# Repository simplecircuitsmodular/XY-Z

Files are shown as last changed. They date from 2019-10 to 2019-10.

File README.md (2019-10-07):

# XY-Z

This is a 16 step 2 dimensional CV sequencer. Each step is controlled by a potentiometer. The pots are laid out in a 4x4 grid, and 2 inputs (X and Y) allow you to move between rows and columns. The module is based on an ATMega 328 and is programed via the Arduino IDE.

## Files
### XY-Z_xx .brd and .sch
These are the board and schematic files needed to manufacture PCBs. Gerbers need to be generated in Eagle for manufacturing.

### XY-Z_xx.md
These are the parts lists for each module. A mouser BOM is available in this file as well.

### XY-Z.ai
These are the panels in Adobe Illustrator format. I make my panels on a laser cutter with 1/8 inch acrylic.

### XY-Z_xx.ino
This is the Arduino source code for the module. It can be uploaded using an ISP programmer.

## Updates

### 01 07OCT19
Initial upload. Design is currently untested.

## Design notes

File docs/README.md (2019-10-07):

# XY-Z

#### [Overview](#overview) | [Design](#design)

### Overview

XY-Z is a 2d, 16 step sequencer. Each step is controlled by a separate potentiometer laid out in a 4x4 array. 2 inputs (X and Y) allow the user to cycle through rows and columns using trigger inputs.

### Design

The core of this module is the potentiometer array. Rows are selected using digital pins on an ATMega 328, and columns are selected using an analog multiplexer. The output is connected to an opamp buffer and varies form 0v-5vdc.

### Buy

I'll be updating this part soon with a link to buy PCBs on Reverb. For the time being you can email me to purchase development PCBs at a discount. These will be fully functional but have minor issues.

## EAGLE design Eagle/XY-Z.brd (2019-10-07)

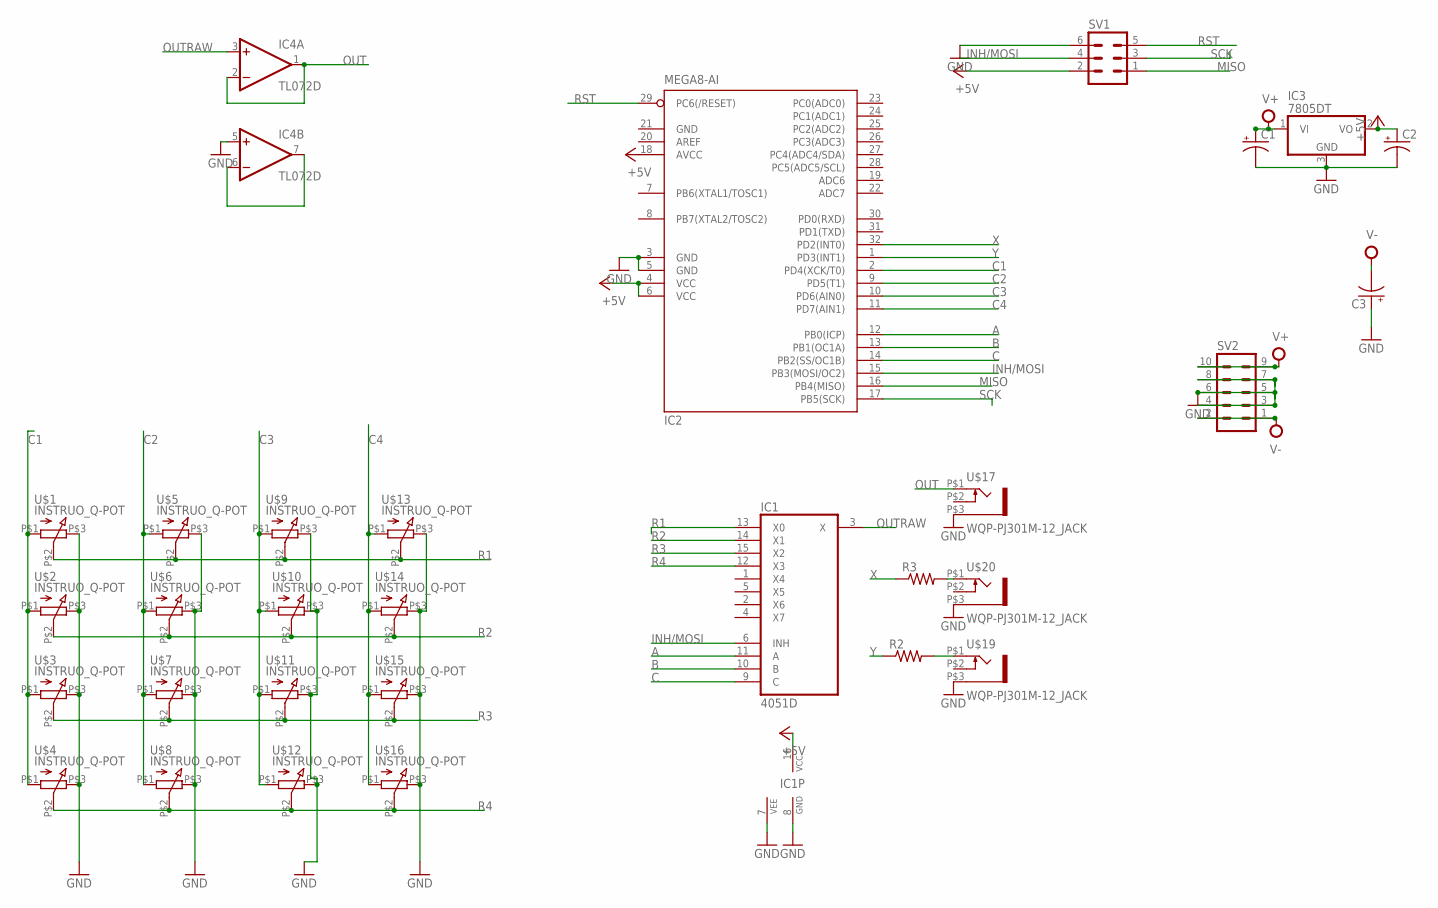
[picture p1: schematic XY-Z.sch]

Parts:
C1, C2, C3: CPOL-US153CLV-0505; 153CLV-0505
IC1: 4051D; SO16
IC2: MEGA8-AI; TQFP32-08
IC3: 7805DT; TO252
IC4: TL072D; SO08
R2, R3: R-US_M0805; M0805
SV1: MA03-2
SV2: MA05-2
U$1, U$2, U$3, U$4, U$5, U$6, U$7, U$8, U$9, U$10, U$11, U$12, U$13, U$14, U$15, U$16: INSTRUO_Q-POT
U$17, U$19, U$20: WQP-PJ301M-12_JACK

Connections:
+5V: C2.+, IC1.16 (VCC), IC2.4 (VCC), IC2.6 (VCC), IC2.18 (AVCC), IC3.2 (VO), SV1.2
A: IC1.11 (A), IC2.12 (PB0(ICP))
B: IC1.10 (B), IC2.13 (PB1(OC1A))
C: IC1.9 (C), IC2.14 (PB2(SS/OC1B))
C1: IC2.2 (PD4(XCK/T0)), U$1.P$1 (1), U$2.P$1 (1), U$3.P$1 (1), U$4.P$1 (1)
C2: IC2.9 (PD5(T1)), U$5.P$1 (1), U$6.P$1 (1), U$7.P$1 (1), U$8.P$1 (1)
C3: IC2.10 (PD6(AIN0)), U$9.P$1 (1), U$10.P$1 (1), U$11.P$1 (1), U$12.P$1 (1)
C4: IC2.11 (PD7(AIN1)), U$13.P$1 (1), U$14.P$1 (1), U$15.P$1 (1), U$16.P$1 (1)
GND: C1.-, C2.-, C3.+, IC1.7 (VEE), IC1.8 (GND), IC2.3 (GND), IC2.5 (GND), IC2.21 (GND), IC3.3 (GND), IC4.5 (+IN), SV1.6, SV2.3, SV2.4, SV2.5, SV2.6, SV2.7, SV2.8, U$1.P$3 (3), U$2.P$3 (3), U$3.P$3 (3), U$4.P$3 (3), U$5.P$3 (3), U$6.P$3 (3), U$7.P$3 (3), U$8.P$3 (3), U$9.P$3 (3), U$10.P$3 (3), U$11.P$3 (3), U$12.P$3 (3), U$13.P$3 (3), U$14.P$3 (3), U$15.P$3 (3), U$16.P$3 (3), U$17.P$3 (1), U$19.P$3 (1), U$20.P$3 (1)
INH/MOSI: IC1.6 (INH), IC2.15 (PB3(MOSI/OC2)), SV1.4
MISO: IC2.16 (PB4(MISO)), SV1.1
unnamed: R2.2, U$19.P$1 (2)
unnamed: R3.2, U$20.P$1 (2)
unnamed: IC4.6 (-IN), IC4.7 (OUT)
OUT: IC4.1 (OUT), IC4.2 (-IN), U$17.P$1 (2)
OUTRAW: IC1.3 (X), IC4.3 (+IN)
R1: IC1.13 (X0), U$1.P$2 (2), U$5.P$2 (2), U$9.P$2 (2), U$13.P$2 (2)
R2: IC1.14 (X1), U$2.P$2 (2), U$6.P$2 (2), U$10.P$2 (2), U$14.P$2 (2)
R3: IC1.15 (X2), U$3.P$2 (2), U$7.P$2 (2), U$11.P$2 (2), U$15.P$2 (2)
R4: IC1.12 (X3), U$4.P$2 (2), U$8.P$2 (2), U$12.P$2 (2), U$16.P$2 (2)
RST: IC2.29 (PC6(/RESET)), SV1.5
SCK: IC2.17 (PB5(SCK)), SV1.3
V+: C1.+, IC3.1 (VI), IC4.8 (V+), SV2.9, SV2.10
V-: C3.-, IC4.4 (V-), SV2.1, SV2.2
X: IC2.32 (PD2(INT0)), R3.1
Y: IC2.1 (PD3(INT1)), R2.1

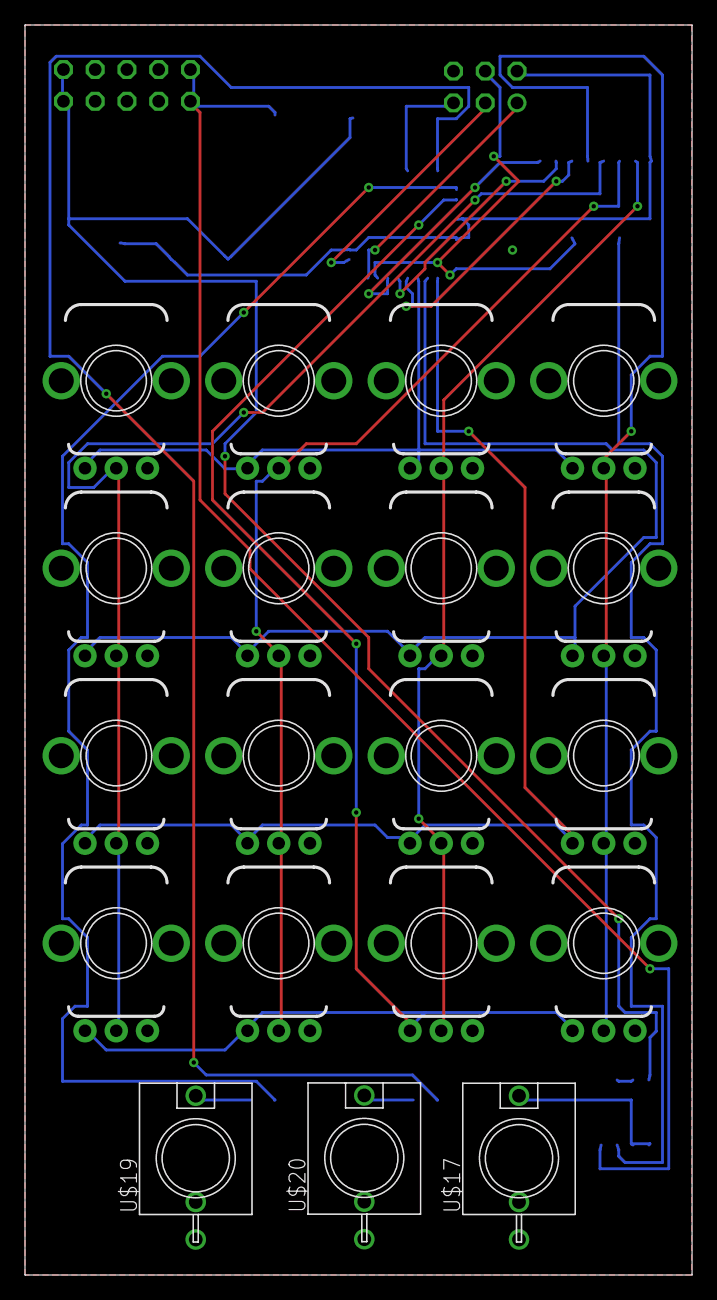
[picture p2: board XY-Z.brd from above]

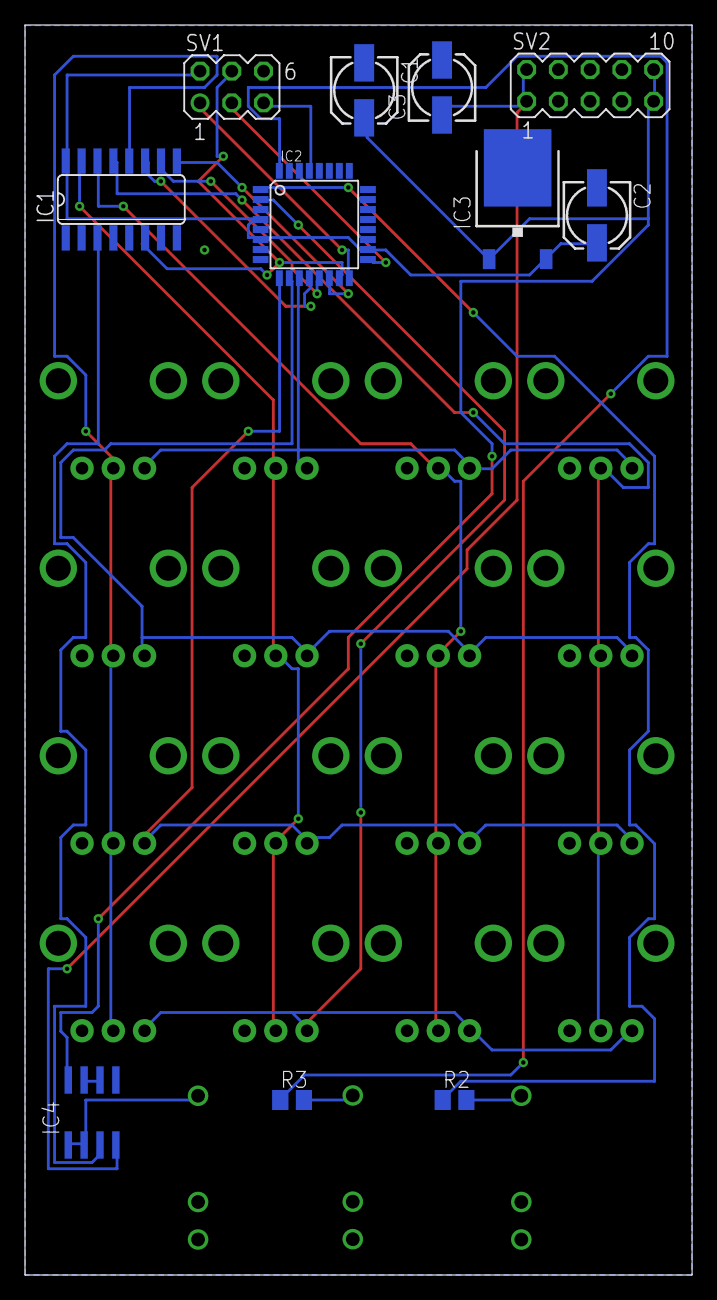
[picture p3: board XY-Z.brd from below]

Board: 2 copper layers, 53.4 x 100.0 mm, 30 parts (11 on the bottom side), 26 nets.
